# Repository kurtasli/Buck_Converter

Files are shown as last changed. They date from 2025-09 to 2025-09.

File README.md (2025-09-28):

# Buck_Converter
 28V Input, 3.3V 3A Output, Step-Down DC-DC Converter

 The design was carried out using the Altium Designer program.

## Board View

<div style="display: flex; align-items: center;">
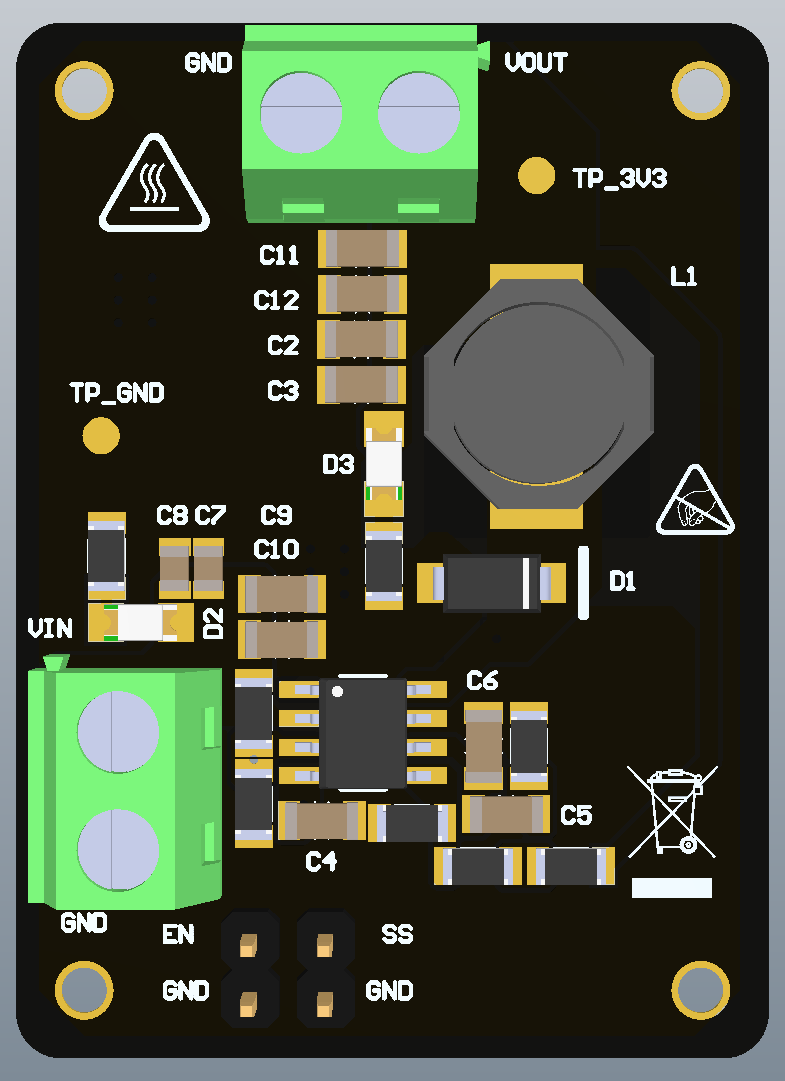
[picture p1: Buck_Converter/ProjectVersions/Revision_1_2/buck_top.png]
  
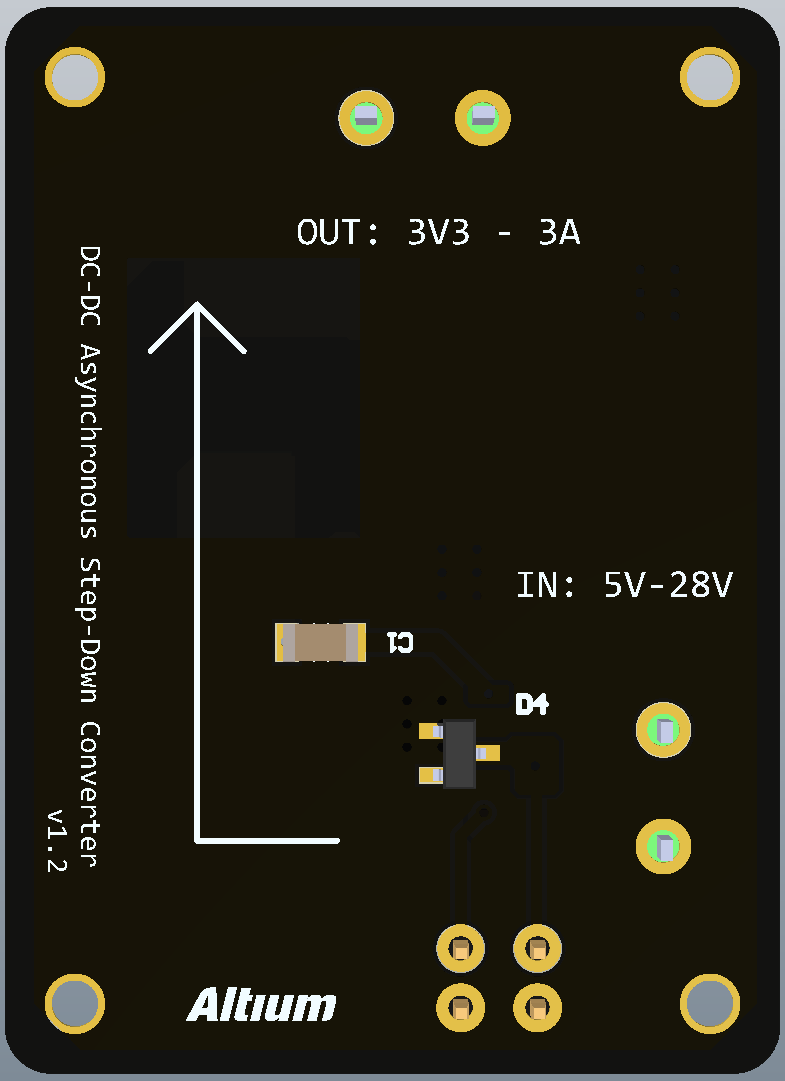
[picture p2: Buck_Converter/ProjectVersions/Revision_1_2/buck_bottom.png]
  
</div>

## Block Diagram

<p align="left">
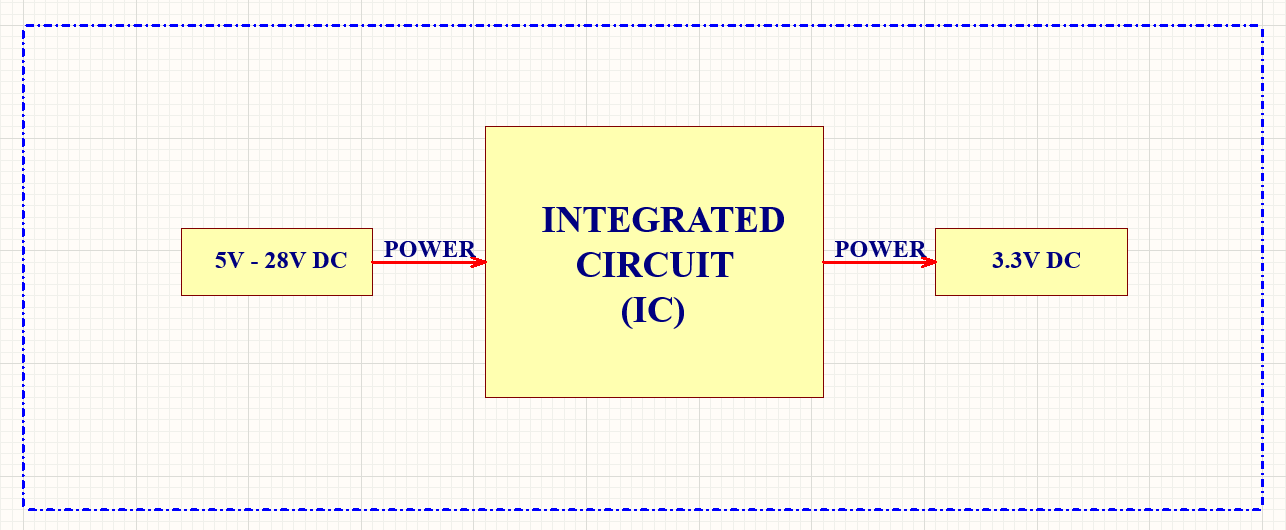
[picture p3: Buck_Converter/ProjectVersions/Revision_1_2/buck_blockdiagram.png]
  
</p>

Red lines refer to POWER LINE.

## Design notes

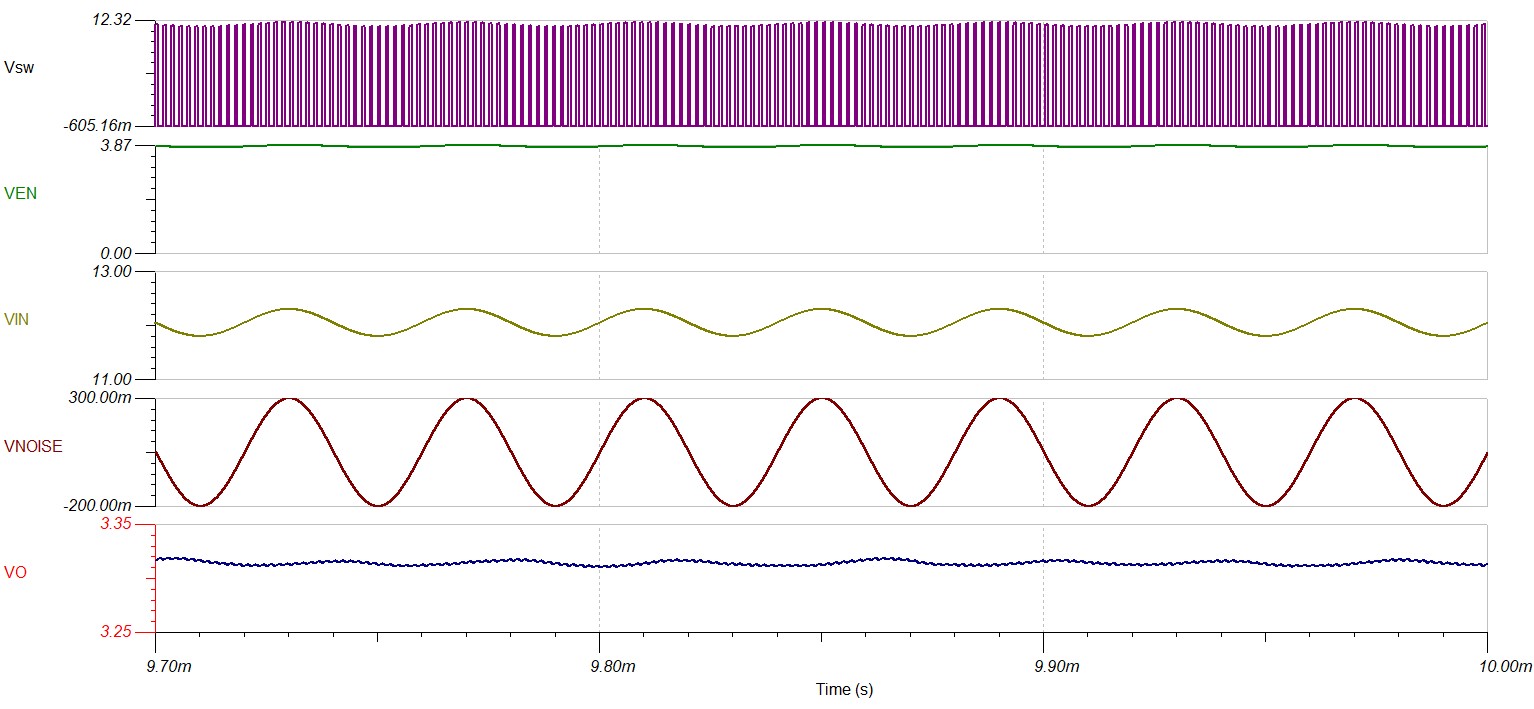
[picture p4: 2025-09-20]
Buck_Converter/ProjectVersions/Revision_1_2/Simulation/scenario3.jpg

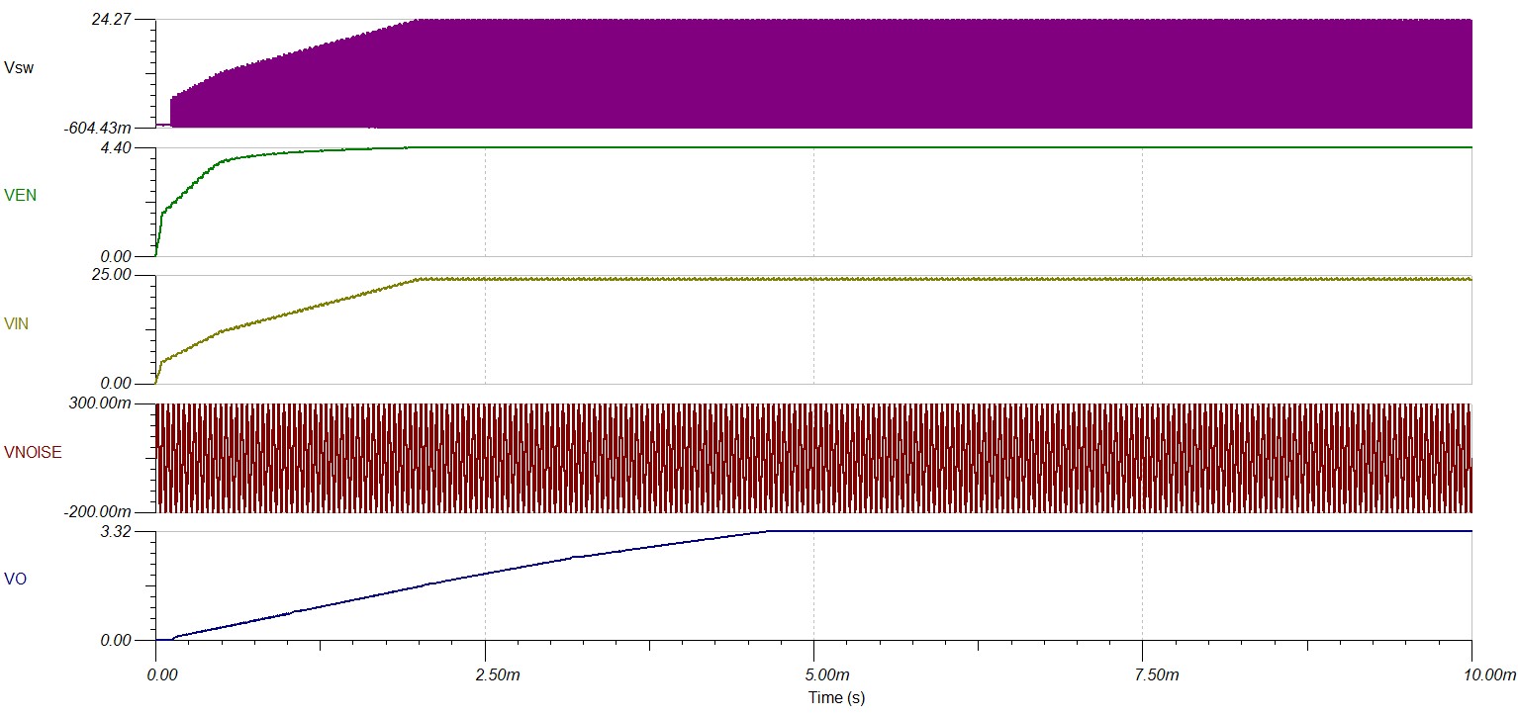
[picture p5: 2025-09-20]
Buck_Converter/ProjectVersions/Revision_1_2/Simulation/scenario2.jpg

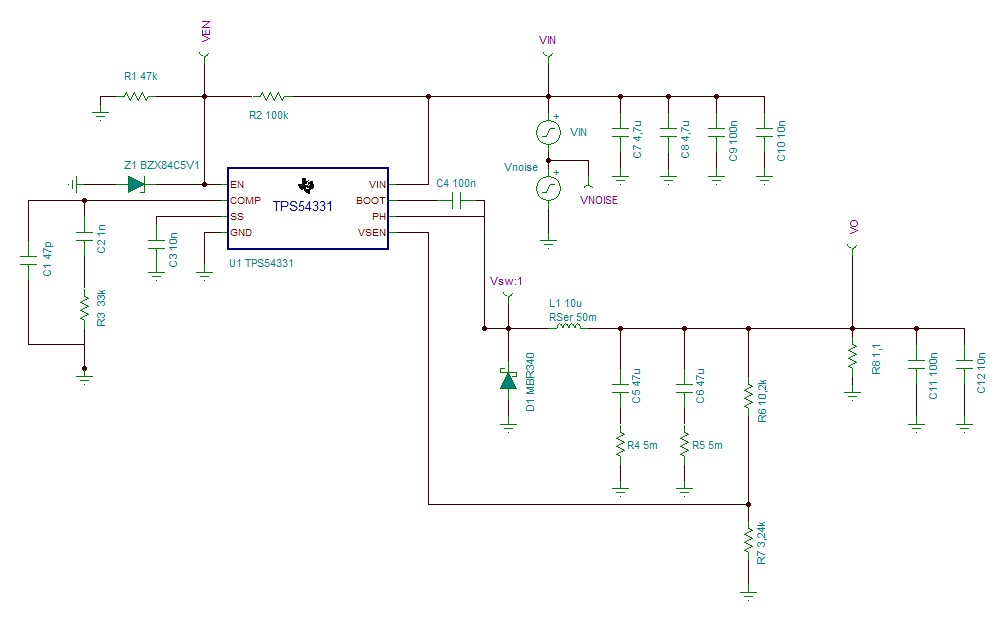
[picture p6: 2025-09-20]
Buck_Converter/ProjectVersions/Revision_1_2/Simulation/BUCK_SIM_TEMEL.JPG

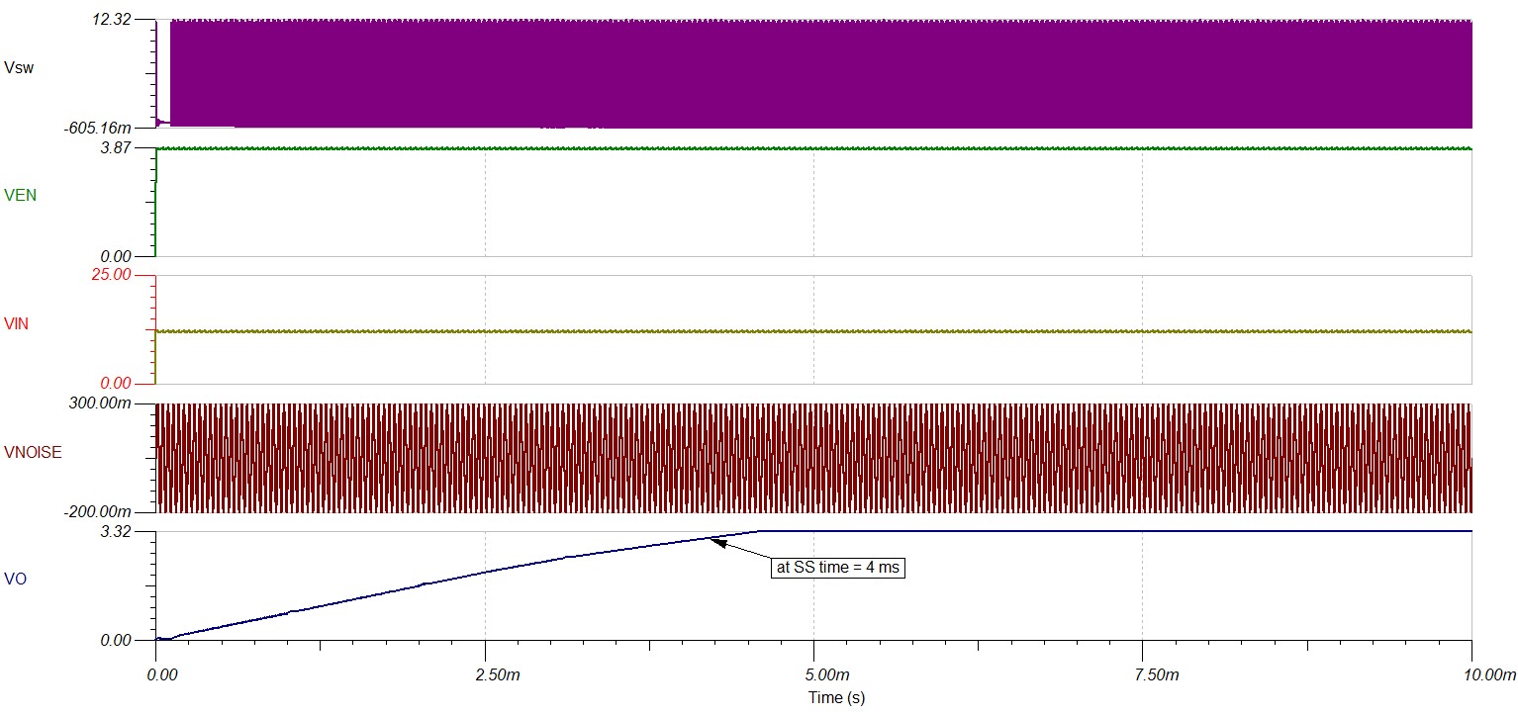
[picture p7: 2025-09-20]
Buck_Converter/ProjectVersions/Revision_1_2/Simulation/scenario1.jpg

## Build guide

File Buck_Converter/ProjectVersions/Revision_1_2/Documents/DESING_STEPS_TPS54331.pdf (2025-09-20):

# BUCK CONVERTER DESIGN (DATASHEET REFERENCED)

# Design Parameters

## V(IN) = 5-28V V(OUT) = 3.3V

I(OUT)= 3A

## Efficieny = %90+

Prepared by: Aslı Kurt

* The TPS54331 IC meeting these criteria was selected for use in the design.

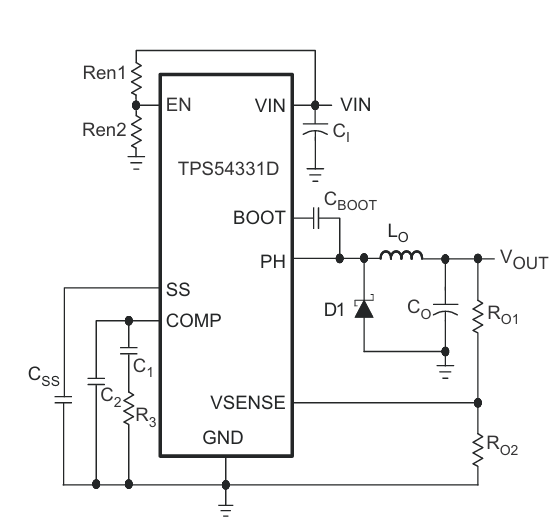
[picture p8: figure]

Figure 1. Simplified Schematic

## Design Steps

1- Feedback Resistors

- Determine the R(O1) & R(O2) by using V(OUT) = 3.3V, V(REF) = 0.8V and Equation 1.

VOUT = VREF. (

RO1

RO2

+ 1) | Equation 1
| R(O1) = 10kΩ and R(O2) = 3.2kΩ

2- Input Capacitors

- Determine the C(IN) by using ∆VIN = 0.15mV, ESR(MAX)=2mΩ and Equation 2.

ΔVIN =

IOUT(MAX)×0.25

CBULK×FSW

+ (IOUT(MAX) × ESR(MAX)

) | Equation 2

CBULK= 9.14 µF, so input capacitor can be divided into two separated capacitors by 4.7 µF.

3- Inductor

- KIND is a coefficient that represents the amount of inductor ripple current relative to the maximum output current can be selected by using Equation 3.
- In general, this value is at the discretion of the designer; however, the following guidelines may be used. For designs using low-ESR output capacitors, such as ceramics, a value as high as KIND = 0.3 can be used. When using higher ESR output capacitors, KIND = 0.2 yields better results. For this design example, use KIND = 0.3 and the minimum inductor value is calculated as 5.7 μH. For this design, a large value was selected: 10 μH.

LMIN =

VOUT(MAX) × (VIN(MAX) − VOUT)

VIN(MAX) × KIND × IOUT × FSW

Equation 3

L = 10 μH

- For the output filter inductor, do not exceed the RMS current and saturation current ratings. These calculations can made with Equation 4, Equation 5 and Equation 6.

ILPP =

VOUT×(VIN(MAX)−VOUT)

VIN(MAX)×LOUT×FSW×0.8

Equation 4

ILRMS = √IOUT(MAX)
2 | +

1
12

× ILPP

2 | Equation 5

ILPK = IOUT(MAX) +

ILPP
2

Equation 6

ILPP = 580mA, ILRMS = 3A, ILPK = 3.29A

4- Output Capacitors

- There are some critical parameters such as DC voltage rating, ripple current rating, and equivalent series resistance (ESR). Minimum capacitor value can be calculated by using Equation 7.
- Consider the relationship between the desired closed-loop crossover frequency of the design and LC corner frequency of the output filter.

- In general, keeping the closed-loop crossover frequency at less than 1/5 of the switching frequency is desired. With high switching frequencies such as the 570-kHz frequency of this design, internal circuit limitations of the TPS54331 device limit the practical maximum crossover frequency to approximately 25 kHz. In general, the closed-loop crossover frequency must be higher than the corner frequency determined by the load impedance and the output capacitor.

COMIN =

1

2×π×RO×FCO(MAX)

, where RO =

VO
IO

Equation 7

RO=1.1Ω, COMIN = 5.8 µH

- This value may not satisfy the output ripple voltage requirement. The output ripple voltage consists of two components: the voltage change because of the charge and discharge of the output filter capacitance and the voltage change because the ripple current times the ESR of the output filter capacitor. These can be calculated by using Equation 8.,Equation 9 and Equation 10.

VOPP = ILPP × (

D−0.5
4×FSW×CO
+ RESR) | Equation 8

ESRMAX =

VOPP(MAX)
ILPP

−

D−0.5
4⋅FSW⋅CO

Equation 9

ICOUTRMS = √
1
12

×

VOUT⋅(VIN(MAX)−VOUT)

VIN(MAX)

⋅LOUT⋅FSW⋅NC

Equation 10

CO = 5.8µF | VIN = 5V | VIN = 28V
VOPP (mV) | 8 | 17.9
ESRMAX (mΩ) | 1.7 | -15*
ICOUTRMS (mA) | 206 | 206
Table 1. Used minimum capacitor value

* Obtained negative resistor. This means the minimum capacitor value is not enough. So bulkier capacitor must be used.

To overcome the problem, it is decided to use 2x47uF capacitor. In addition, the equivalent ESR (equivalent series resistance) value of the capacitors has been halved.

Co = 94µF | Vin = 5V | Vin = 28V
VOPP (mV) | 1.59 | 2.19
ESRMAX (mΩ) | 1.99 | 1.99
ICOUTRMS (mA) | 145.88 | 145.88
Table 2. Modified capacitor value

5- Compensation Design
- First, The PL (Phase Loss) must be calculated. PL means the lost phase value when filtering output of the circuit by using inductors and capacitors (LC Filter). This can be calculating with using Equation 11.

PL =

π
180

× (arctan(2π ⋅ FCO ⋅ RESR ⋅ CO) − arctan(2π ⋅ FCO ⋅ RO ⋅ CO)) Equation 11

Let FCO=25kHz, RESR = 2mΩ/2=1mΩ (parallel capacitors’ resistance), CO = 54µF (DC bias) PL=-1.456 rad/s = -83.42°

- Phase Boost (PB) is the additional phase angle that the compensation network must add to the system at the crossover frequency. In other words, it is added to compensate for the negative phase loss caused by the buck converter's output filter and modulator's phase loss (PL). Phase margin is selected generally 60-70°. PB is calculated by using Equation 12.
PB = PM − 90∘ − PL | Equation 12
PB=63.5°
- Zero (FZ1): The point that increases the phase positively as frequency increases (before the crossover).
Pole (FP1): The point that decreases the phase as frequency increases (after the crossover).
The zero and pole are placed symmetrically around the crossover frequency. The coefficient (k) that determines this symmetry can be found using Equation 15. The zero and pole values of the circuit are found using Equation 14 and Equation 13, respectively.

k = tan (

PB
2

+ 45∘

) | Equation 13

FZ1 =

FCO
k

Equation 14

FP1 = FCO × k | Equation 15
| k = 4.25, FZ1 = 5.95kHz, FP1 = 105kHz
- To obtain RZ, CZ and CP; Equation 16, Equation 17, and Equation 18 can be used respectively.

RZ =

2⋅π⋅FCO⋅VO⋅CO⋅ROA GMCOMP⋅VGGM⋅VREF | Equation 16

CZ =

1
2⋅π⋅FZ1⋅RZ

Equation 17

CP =

1
2⋅π⋅FP1⋅RZ

Equation 18

RZ= 29.157kΩ, CZ = 917.4pF, CP = 51.99pF so, RZ = 33kΩ, CZ = 1000pF, CP 47pF

6- Bootstrap Capacitor

- Bootstrap capacitor is selected 0.1µF for necessary. The bootstrap capacitor must be a high-quality ceramic type with X7R or X5R grade dielectric for temperature stability.

7- Catch Diode

- In buck converters, when the high-side MOSFET is turned off, current must continue to flow through the inductor. The diode that guides this current is called a catch diode. In other words, when the MOSFET is off, the inductor current flows through this diode. This ensures that the inductor's energy is conserved and the output operates properly.

- The selected diode must meet the absolute maximum ratings for the application. In a circuit switching at high frequencies, diodes with short reverse recovery times, that is, diodes that do not store charge in reverse voltage, should be preferred. Furthermore, for low power consumption, it is preferable to select diodes with low forward voltage drop. Schottky diodes are ideal for this purpose. There are important criteria for diode selection.
- Reverse Voltage - It is the maximum voltage that the diode can withstand in reverse bias. This can be calculated by using Equation 19.
VR > VPH(MAX) = VIN(MAX) + 0.5 | Equation 19

VR = 28.5V

- Peak Current-It is the maximum current that the diode can carry. This can be calculated by using Equation 20.

Ipeak > IOUT(MAX) +

ILPP
2

Equation 20

IPEAK = 3.29A

B340A was selected, with a reverse voltage of 40 V, forward current of 3 A, and a forward-voltage drop of 0.5 V.

8- Slow-Start Capacitors

- Programming the slow-start time externally is highly recommended because no slow-start time is implemented internally. The TPS54331 device effectively uses the lower voltage of the internal voltage reference or the SS pin voltage as the reference voltage of the power supply that is fed into the error amplifier and regulates the output accordingly. A capacitor (CSS) on the SS pin to ground implements a slow-start time. The TPS54331 device has an internal pullup current-source of 2 μA that charges the external slow-start capacitor.
- The slow-start time must be set between 1 ms to 10 ms to ensure good start-up behavior. The value of the slow-start capacitor must not exceed 27 nF. For this reason slow-start capacitor value is selected as 10nF. VREF is 0.8 V and ISS is 2 μA.

TSSms =

CSS(nF)∗VREF(V)

ISS(µA)

Equation 21
- CSS(nF)= 10nF, TSSms= 4ms

9- Enable Resistors

- Additionally, the maximum voltage rating of the TPS54331 IC's Enable pin must be adjusted to avoid violating the maximum voltage rating limits. The maximum voltage is clearly stated as 6V in the datasheet. Because high VIN voltages can exceed the maximum rating limit via the voltage divider circuit, a 5.1V zener diode has been added between this pin and ground for safety. The BZX84C5V1 zener diode was selected with a 5.1V zener voltage and a power rating of 350mW.

VOUT = VIN.

R2
R1+R2

Equation 22

Ren1 = 100kΩ, Ren2 = 47kΩ

10- Power Consumption

- The following equations show how to estimate the device power dissipation under continuous-conduction mode (CCM) operations. These formulas must not be used if the device is working in the discontinuous-conduction mode (DCM) or pulse-skipping Eco-mode.

Pcon = IOUT

2
⋅ RDS(on)

⋅

VOUT

VIN

Equation 23

Psw = 0.5 × 10

−9
⋅ VIN

2

⋅ IOUT ⋅ fSW | Equation 24

Pgc = 22.8 × 10⁻⁹

⋅ fSW | Equation 25

Pq = 0.11 × 10⁻³

⋅ VIN | Equation 26
Ptot = Pcon + Psw + Pgc + Pq | Equation 27
VIN (V) | 5 | 12 | 20 | 28
Pcon(W) | 0.475 | 0.198 | 0.119 | 0.085
Psw(W) | 0.021 | 0.123 | 0.342 | 0.670
Pgc(W) | 0.013 | 0.013 | 0.013 | 0.013
Pq (W) | 0.0006 | 0.0013 | 0.0022 | 0.0031
Ptot(W) | 0.510 | 0.355 | 0.476 | 0.771
Table.3 Power Dissipation due to VIN
